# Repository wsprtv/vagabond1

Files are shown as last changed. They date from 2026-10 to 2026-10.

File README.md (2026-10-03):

# Vagabond1 WSPR Transmitter

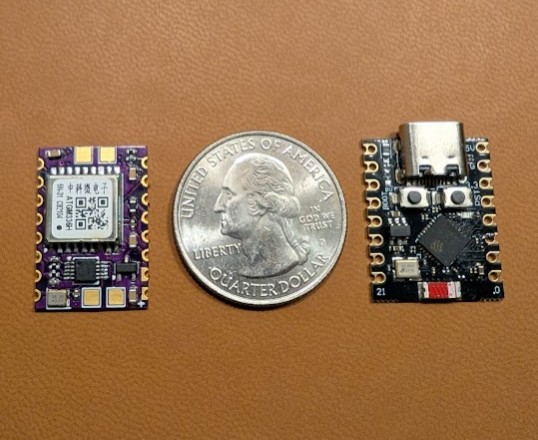
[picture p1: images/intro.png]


Vagabond1 is a tiny WSPR transmitter that piggybacks on the popular ESP32 C3
Super Mini board. It contains only 15 components (including 11 passives) and
can be assembled by hand. Vagabond1 is fully supported by
[Nomad](https://github.com/wsprtv/nomad) firmware.

## Links

- [Schematic](https://wsprtv.com/vagabond1/docs/vagabond1.pdf)
- [Interactive BOM](https://wsprtv.com/vagabond1/docs/ibom.html)
- [KiCad files](https://github.com/wsprtv/vagabond1/tree/main/kicad)
- [Gerbers](https://github.com/wsprtv/vagabond1/tree/main/gerbers)
- [Nomad firmware](https://github.com/wsprtv/nomad)
- [ESP32 C3 Super Mini Documentation](https://www.espboards.dev/esp32/esp32-c3-super-mini/)

## Assembly

In addition to the [Si5351A](https://www.digikey.com/en/products/detail/skyworks-solutions-inc/SI5351A-B-GTR/4069612) or
[MS5351M](https://www.lcsc.com/product-detail/C1509083.html)
clock generator and [ATGM336H-5N31](https://www.lcsc.com/product-detail/C90770.html) GPS
module, Vagabond1 uses the
[APX803S05-26SA](https://www.digikey.com/en/products/detail/diodes-incorporated/APX803S05-26SA-7/7352746)
voltage monitor and the
[HSB221S 26MHz TCXO](https://www.digikey.com/en/products/detail/harmony-electronics-corp-h-ele/TC2S026000DCCHE-T/16733095).
Both are readily available on DigiKey, though several pin-compatible
alternatives can be easily substituted.

All ceramic capacitors should be rated for at least 6V.

Unpopulated PCBs can be ordered from [OSH Park](https://oshpark.com).
Upload the
[KiCad board file](https://wsprtv.com/vagabond1/kicad/vagabond1.kicad_pcb) and select the
**0.8mm thickness, 2oz copper** option. Stencils can be ordered from
[OSH Stencils](https://oshstencils.com) or cut at home using a Silhouette or
Cricut machine.

After applying solder paste and
placing the components, I reflow the boards on an electric skillet. Assembling
a batch of three boards takes roughly an hour.

When soldering Vagabond1 and ESP32 C3 Super Mini boards together, orient them
so that the GPS module **faces away** from the USB-C port.

## ESP32 C3 Super Mini Modifications

The ESP32 board requires two modifications when powered with solar cells.

1. The RESET line on the ESP32 needs to be routed to pin 2 to enable voltage
monitoring. Connect the two pads with a wire as shown below:

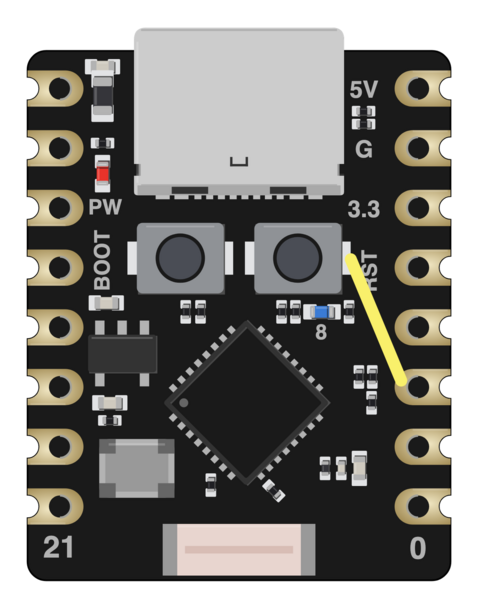
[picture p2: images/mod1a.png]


2. Replace the reverse polarity protection diode on VSYS with a 0-ohm
resistor or a solder bridge to eliminate an unnecessary 0.2V drop. Also,
consider removing the always-on power LED or the associated current-limiting
resistor (or both) to save ~0.8 mA. The image below shows the location
of the diode (top highlighted component), followed by the resistor
and the LED.

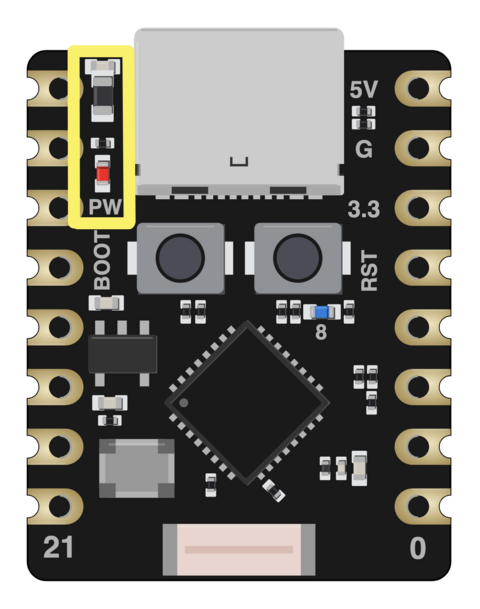
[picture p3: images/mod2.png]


## Connections

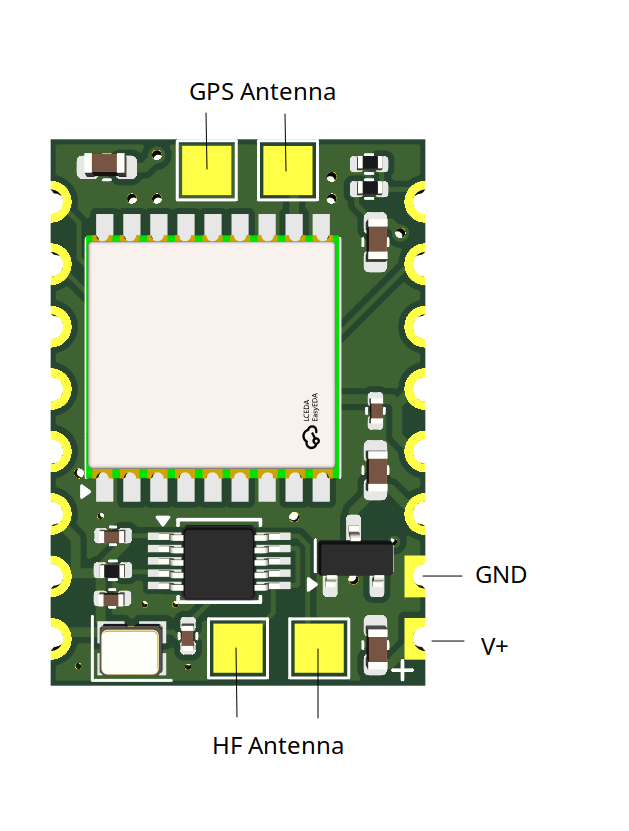
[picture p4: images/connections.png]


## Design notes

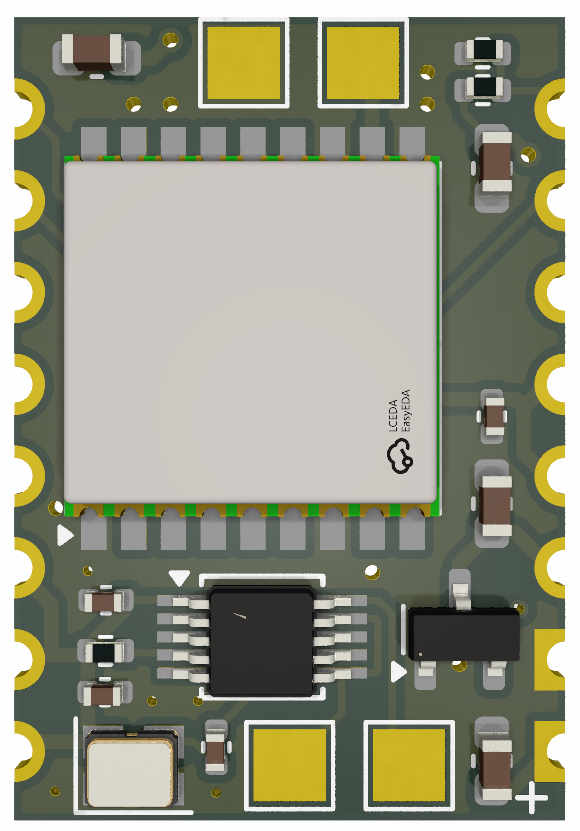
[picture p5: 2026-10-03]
images/vagabond1.png

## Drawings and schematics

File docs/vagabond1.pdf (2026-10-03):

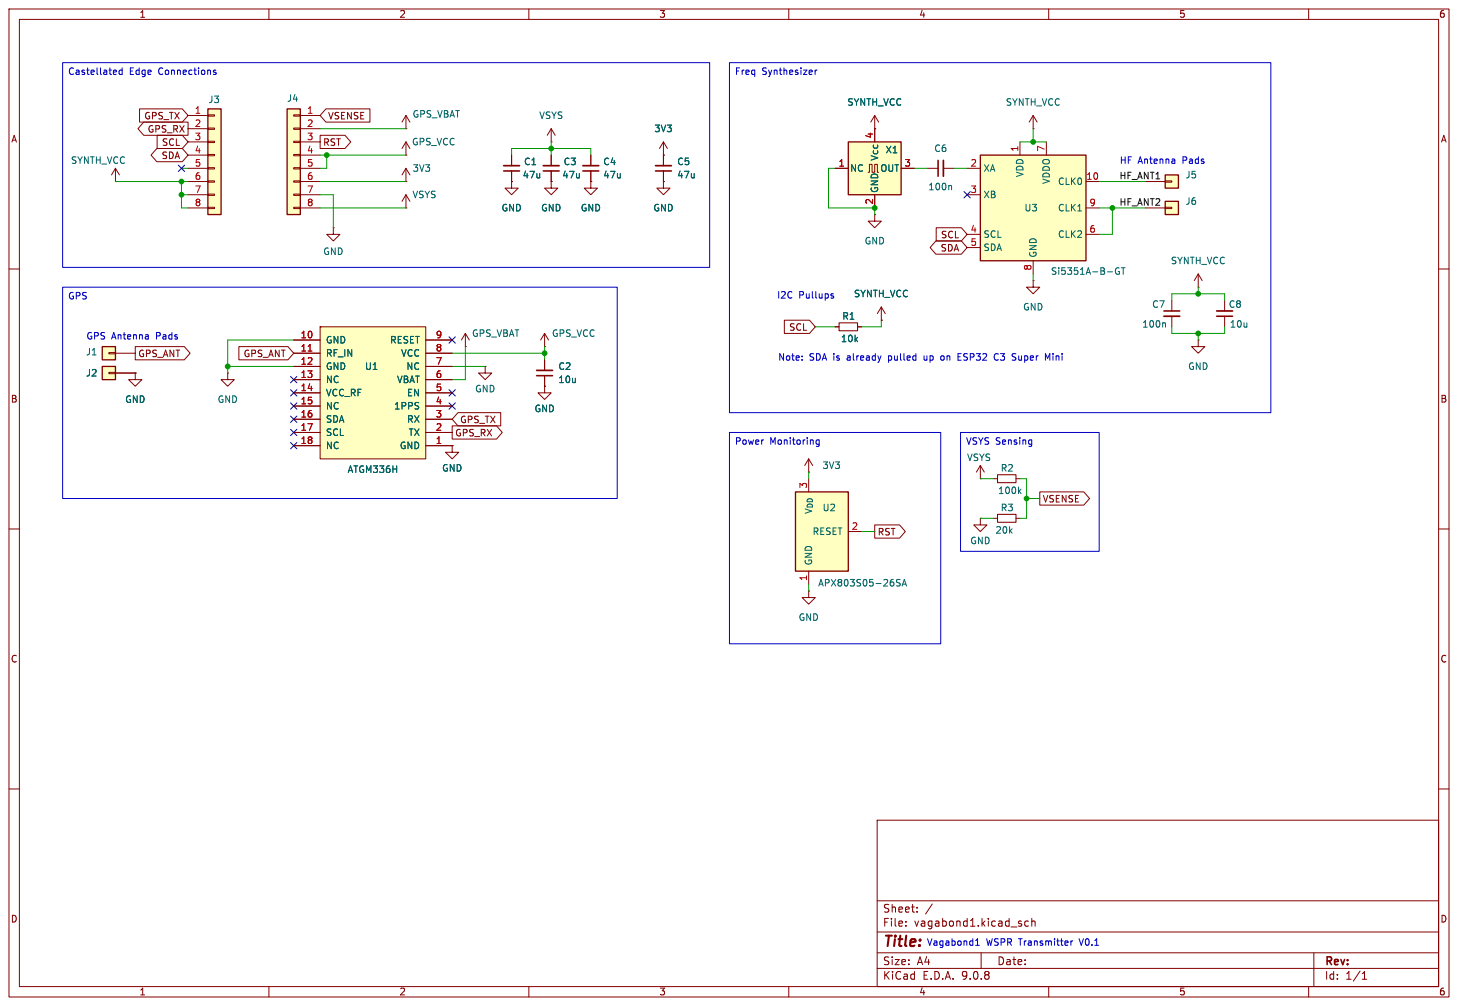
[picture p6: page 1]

Id: 1/1 Title: File: vagabond1.kicad_sch Sheet: /

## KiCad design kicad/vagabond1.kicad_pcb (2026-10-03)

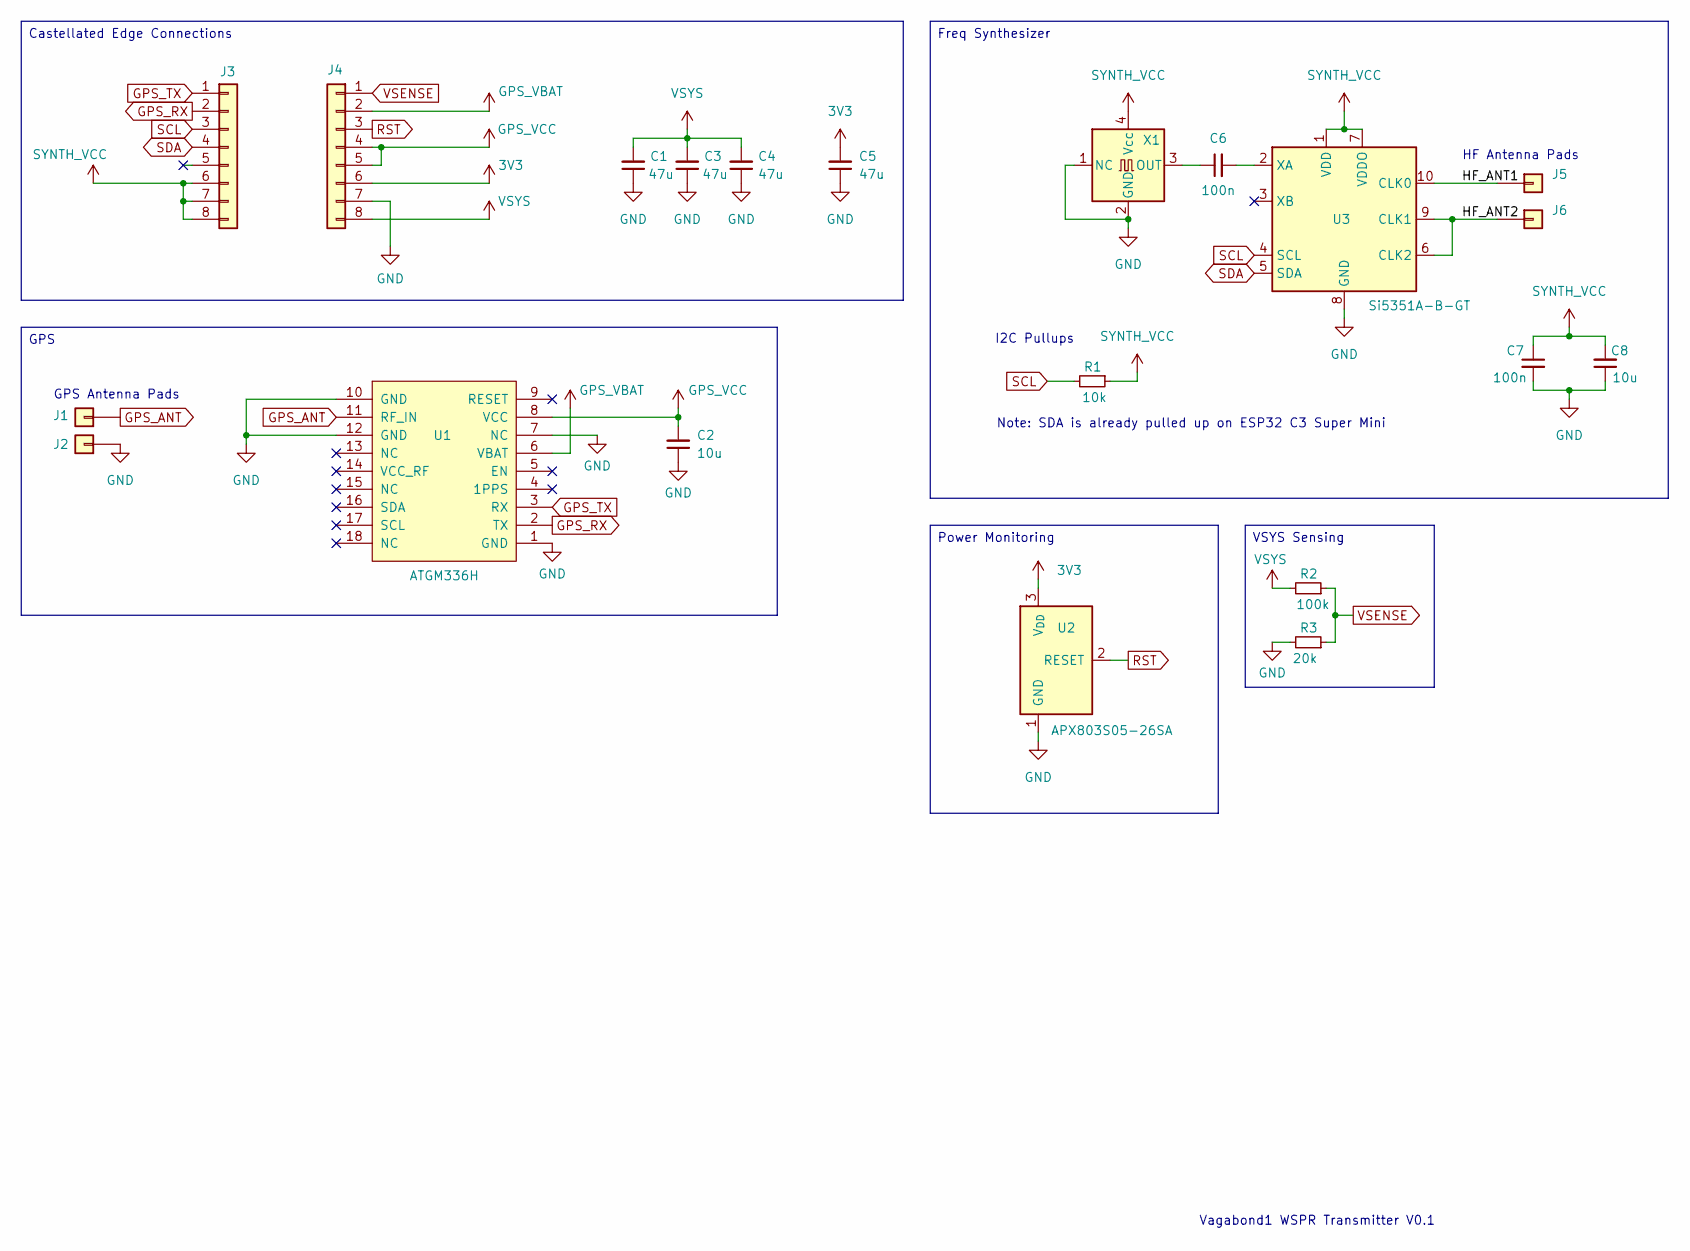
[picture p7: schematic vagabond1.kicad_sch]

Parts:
C1, C3, C4, C5: 47u; C_0603_1608Metric
C2, C8: 10u; C_0402_1005Metric
C6, C7: 100n; C_0402_1005Metric
J1, J2, J5, J6: Conn_01x01_Pin; TestPoint_Pad_2.0x2.0mm
J3, J4: Conn_01x08_Pin; PinHeader_1x08_P2.54mm_Vertical
R1: 10k; R_0402_1005Metric
R2: 100k; R_0402_1005Metric
R3: 20k; R_0402_1005Metric
U1: ATGM336H
U2: APX803S05-26SA; SOT-23
U3: Si5351A-B-GT; MSOP-10_3x3mm_P0.5mm
X1: TCXO; TCXO_4Pin_2.5x2.0mm

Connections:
3V3: C5.2, J4.6, U2.3 (V_{DD})
/HF_ANT1: J5.1, U3.10 (CLK0)
/HF_ANT2: J6.1, U3.6 (CLK2), U3.9 (CLK1)
GND: C1.1, C2.1, C3.1, C4.1, C5.1, C7.2, C8.1, J2.1, J4.7, R3.2, U1.1 (GND), U1.7 (NC), U1.10 (GND), U1.12 (GND), U2.1 (GND), U3.8 (GND), X1.1 (NC), X1.2 (GND)
GPS_ANT: J1.1, U1.11 (RF_IN)
GPS_RX: J3.2, U1.2 (TX)
GPS_TX: J3.1, U1.3 (RX)
GPS_VBAT: J4.2, U1.6 (VBAT)
GPS_VCC: C2.2, J4.4, J4.5, U1.8 (VCC)
unnamed: C6.2, U3.2 (XA)
unnamed: C6.1, X1.3 (OUT)
RST: J4.3, U2.2 (RESET)
SCL: J3.3, R1.2, U3.4 (SCL)
SDA: J3.4, U3.5 (SDA)
SYNTH_VCC: C7.1, C8.2, J3.6, J3.7, J3.8, R1.1, U3.1 (VDD), U3.7 (VDDO), X1.4 (Vcc)
VSENSE: J4.1, R2.1, R3.1
VSYS: C1.2, C3.2, C4.2, J4.8, R2.2

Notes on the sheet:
Note: SDA is already pulled up on ESP32 C3 Super Mini
Vagabond1 WSPR Transmitter V0.1
I2C Pullups
GPS Antenna Pads
HF Antenna Pads
Freq Synthesizer
Castellated Edge Connections
Power Monitoring
VSYS Sensing
GPS

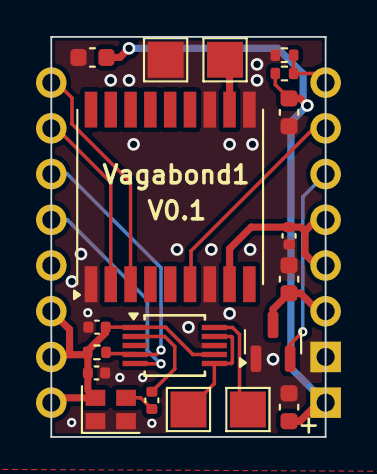
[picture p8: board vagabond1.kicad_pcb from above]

Board: 2 copper layers, 15.2 x 22.2 mm, 21 parts (0 on the bottom side), 17 nets.

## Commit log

2026-10-03 Switching to APX803S05-26SA voltage monitor
    [vagabond1.kicad_pcb, vagabond1.kicad_sch]
2026-10-28 Added a si5351a BOM options, documented power consumption
2026-10-28 Documented 1-wire connections
2026-10-29 Updated power measurements
2026-11-02 Added a 3D-printable solar cell mount
